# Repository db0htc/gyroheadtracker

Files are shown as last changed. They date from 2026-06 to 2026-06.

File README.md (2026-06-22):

# Gyro Headtracker and mouse control device

  This project is a simple gyro-controlled headtracker and general mouse control tool, made for mounting on hats or anything else that follows head movement.
  It started as something i was making for a friend in Star Citizen who had issues with his hands, but he fell more ill and could not play as much.
  I'm putting it here for anyone else who wants a cool home-made headtracker or gyro assist device for FPS games. You can control your gun movements with it, since it uses mouse input. you can even control the gun gimbals in Star citizen while flying with sticks (very accurately, very quickly), but i do not recommend it. It was simpler to fly normally and use it as a head tracker

  Included in the repository are files for 3D printing the mount for the head tracker PCBs and buttons

 # Bill of Materials:
  
Adafruit ESP32-S3 Feather with 4MB Flash 2MB PSRAM - STEMMA QT / Qwiic PID: 5477
https://www.adafruit.com/product/5477 

Adafruit 9-DOF Orientation IMU Fusion Breakout - BNO085 (BNO080) - STEMMA QT / Qwiic PID: 4754
https://www.adafruit.com/product/4754

STEMMA QT / Qwiic JST SH 4-pin Cable - 100mm Long
https://www.adafruit.com/product/4210 

at the time of this writing, the total cost before shipping is under $50. Not bad for a cheap head tracker with low latency and good accuracy!
Please support Adafruit by buying from them, their code libraries and hardware has made so many projects like this one possible, and
their contributions the arduino ecosystem can not be understated

# Programming:

In the Arduino IDE:
1. install the Adafruit_Tinyusb library
2. install the BNO08x library
3. plug in ESP-32 feather module via USB-C
4. program

# Usage:

1. assemble mount
2. mount mount to hat

3. look at center of monitor and press calibrate button

This project should work with any ESP-32-S3 adjacent board, and any BNO080 gyro using I2C, but i recommend the three links above for plug and play simplicity

The above board is bluetooth capable, enabling a wireless version, but the bluetooth interface for mice is a bit weird and i didn't like it

due to the nature of geometry, the tracking follows a rotational path on a flat surface, so you will get more speed in the center of the screen, but slightly more accuracy and less speed on the edges of the screen. If you have a curved monitor, this is a non issue except on the vertical axis. You might not notice the effect when you edit the variables for mouse control vs head tracking

# Assembly:

the following picture is how i made mine (STL file included, print vertically so the long axis is along the vertical axis of the printer. Designed for printing without supports)

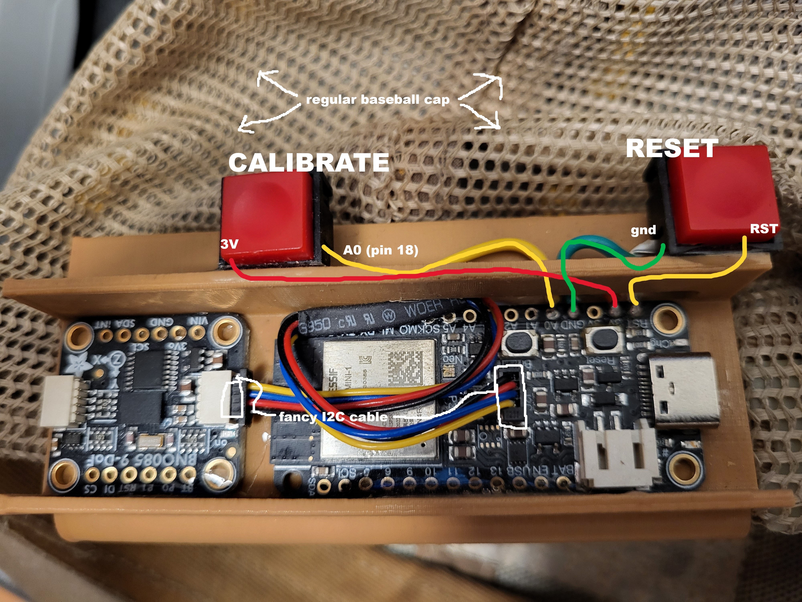
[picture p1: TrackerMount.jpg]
example of mounting

https://github.com/db0htc/gyroheadtracker/blob/main/TrackerMount.jpg

No AI generated code was used in this project. AI was used to look up the normalization formula, which was then hand-typed in

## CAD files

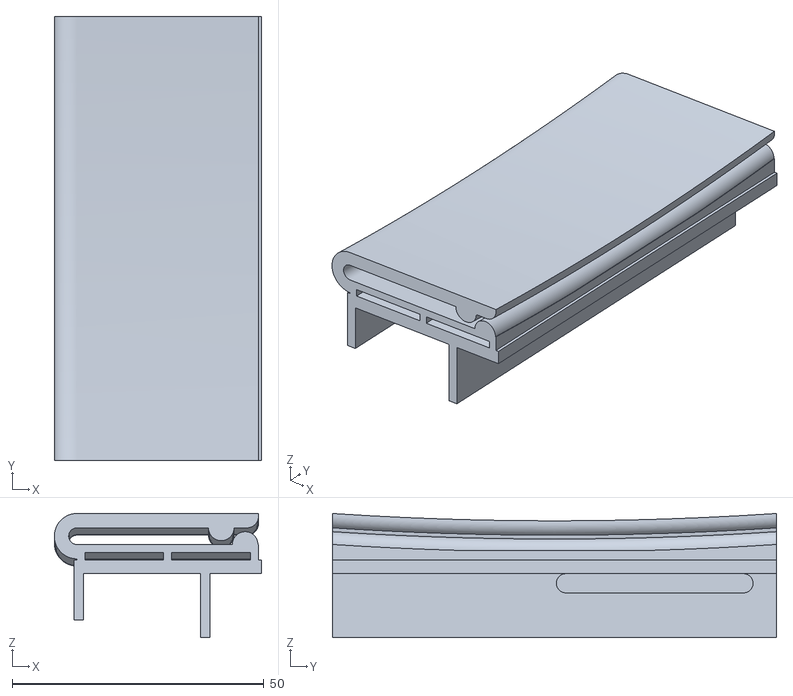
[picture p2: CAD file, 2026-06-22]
diyheadtrackerclip2.STL
41.2 x 88.3 x 24.7

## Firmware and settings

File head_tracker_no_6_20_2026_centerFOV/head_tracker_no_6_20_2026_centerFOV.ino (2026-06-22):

/*
This is a gyro-controlled mouse mover. It also works as a head tracker in some games (i use it for nuclear option and star citizen)
with the right code additions, this could also be used to create a unique joystick input or gamepad input

this used example code as an initial template, originally by Adafruit
who are awesome and deserve good things for how much they bring into the maker community
seriously, chinese products are cheaper but buy Adafruit if you can!

latency is at or less than 10ms (or was)
very accurate, can be tweaked by editing the two variables at the current default values for head tracking:
float FOV = 60;
float sensitivity = 1000;
these variables are found below at lines 64 and 65

an FOV value of 40 and a sensitivity of 500 is better for casual mouse control
FOV value of 40 was obtained by measuring my monitor and distance from my face to the monitor

sensitivity in part is left over from the time i had an absolute position version, 
but it's literally unusable in games due to them using relative positioning of the mouse. 
Might be better for accessibility users on the desktop, but requires additional files i have edited

the included libraries below are necessary for the project to compile

the two pins being used are the reset pin, and pin 18 (A0) for selecting the center of the monitor as the reference point. A0 (pin 18) is pulled low and activated by a button wired to positive
*/
#include <Arduino.h>
#include <Adafruit_BNO08x.h>
#include "Adafruit_TinyUSB.h"

#if defined(ARDUINO_SAMD_CIRCUITPLAYGROUND_EXPRESS) || defined(ARDUINO_NRF52840_CIRCUITPLAY)
const int pin = 4; // Left Button
bool activeState = true;

#elif defined(ARDUINO_FUNHOUSE_ESP32S2)
const int pin = BUTTON_DOWN;
bool activeState = true;

#elif defined PIN_BUTTON1
const int pin = PIN_BUTTON1;
bool activeState = false;

#elif defined(ARDUINO_ARCH_ESP32)
const int pin = 0;
bool activeState = false;

#elif defined(ARDUINO_ARCH_RP2040)
const int pin = D0;
bool activeState = false;
#else
const int pin = A0;
bool activeState = false;
#endif


int16_t lastx = 0;
int16_t lasty = 0;

float rlimitx = 0;
float llimitx = 0;
float ulimity = 0;
float dlimity = 0;
float xcenter = 0;
float ycenter = 0;
float FOV = 60;
float sensitivity = 1000;

const int calbutton = 18;

// HID report descriptor using TinyUSB's template
// Single Report (no ID) descriptor
uint8_t const desc_hid_report[] = {
    TUD_HID_REPORT_DESC_MOUSE()
};

Adafruit_USBD_HID usb_hid;
#define BNO08X_CS 10
#define BNO08X_INT 9
#define FAST_MODE
#define BNO08X_RESET -1

struct euler_t {
  float yaw;
  float pitch;
  float roll;
} ypr;

Adafruit_BNO08x  bno08x(BNO08X_RESET);
sh2_SensorValue_t sensorValue;

sh2_SensorId_t reportType = SH2_GYRO_INTEGRATED_RV;
long reportIntervalUs = 2000;

void setReports(sh2_SensorId_t reportType, long report_interval) {
  if (! bno08x.enableReport(reportType, report_interval)) {
  }
}

void setup(void) {
// for some reason the disconnect/reconnect was necessary on my computer
 digitalWrite(calbutton, HIGH);

 tud_disconnect();

 delay(2000);

 tud_connect();

 delay(2000);

 while (!TinyUSBDevice.isInitialized()) {
    delay(200);
    TinyUSBDevice.begin(0);
  }

 delay(10);     // will pause Zero, Leonardo, etc until serial console opens

  if (!bno08x.begin_I2C()) {
    while (1) { delay(10); }
  }

  setReports(reportType, reportIntervalUs);

  pinMode(pin, activeState ? INPUT_PULLDOWN : INPUT_PULLUP);

  usb_hid.setBootProtocol(HID_ITF_PROTOCOL_MOUSE);
  usb_hid.setPollInterval(2);
  usb_hid.setReportDescriptor(desc_hid_report, sizeof(desc_hid_report));
  usb_hid.setStringDescriptor("TinyUSB Mouse");
  usb_hid.begin();

  if (TinyUSBDevice.mounted()) {
    TinyUSBDevice.detach();
    delay(10);
    TinyUSBDevice.attach();
  }

  delay(100);
}

void quaternionToEuler(float qr, float qi, float qj, float qk, euler_t* ypr, bool degrees = false) {

    float sqr = sq(qr);
    float sqi = sq(qi);
    float sqj = sq(qj);
    float sqk = sq(qk);

    ypr->yaw = atan2(2.0 * (qi * qj + qk * qr), (sqi - sqj - sqk + sqr));
    ypr->pitch = asin(-2.0 * (qi * qk - qj * qr) / (sqi + sqj + sqk + sqr));
    ypr->roll = atan2(2.0 * (qj * qk + qi * qr), (-sqi - sqj + sqk + sqr));

    if (degrees) {
      ypr->yaw *= RAD_TO_DEG;
      ypr->pitch *= RAD_TO_DEG;
      ypr->roll *= RAD_TO_DEG;
    }
}

void quaternionToEulerRV(sh2_RotationVectorWAcc_t* rotational_vector, euler_t* ypr, bool degrees = false) {
    quaternionToEuler(rotational_vector->real, rotational_vector->i, rotational_vector->j, rotational_vector->k, ypr, degrees);
}

void quaternionToEulerGI(sh2_GyroIntegratedRV_t* rotational_vector, euler_t* ypr, bool degrees = false) {
    quaternionToEuler(rotational_vector->real, rotational_vector->i, rotational_vector->j, rotational_vector->k, ypr, degrees);
}

void process_hid() {
  bool btn_pressed = digitalRead(calbutton);

  if (TinyUSBDevice.suspended()) {
    TinyUSBDevice.remoteWakeup();
  }

 if (btn_pressed) {
      delay(100);
        xcenter = ypr.yaw;
        ycenter = ypr.pitch;
        float FOVDIV = FOV / 2;
        ulimity = ycenter - FOVDIV;
        dlimity = ycenter + FOVDIV;
        llimitx = xcenter + FOVDIV;
        rlimitx = xcenter - FOVDIV;
 }
  return;
}

void loop() {

  #ifdef TINYUSB_NEED_POLLING_TASK
  TinyUSBDevice.task();
  #endif

  if (!TinyUSBDevice.mounted()) {
    return;
  }

  static uint32_t ms = 0;
  if (millis() - ms > 10) {
    ms = millis();
    process_hid();
  }

  if (bno08x.wasReset()) {
    setReports(reportType, reportIntervalUs);
  }
  
  if (bno08x.getSensorEvent(&sensorValue)) {
    // in this demo only one report type will be received depending on FAST_MODE define (above)
    switch (sensorValue.sensorId) {
      case SH2_ARVR_STABILIZED_RV:
        quaternionToEulerRV(&sensorValue.un.arvrStabilizedRV, &ypr, true);
      case SH2_GYRO_INTEGRATED_RV:
        // faster (more noise?)
        quaternionToEulerGI(&sensorValue.un.gyroIntegratedRV, &ypr, true);
        break;
    }
    if (usb_hid.ready()) {
    uint8_t const report_id = 0; // no ID
    int16_t const x = (1 - ((ypr.yaw - rlimitx) / (llimitx - rlimitx))) * sensitivity;
    int16_t const y = ((ypr.pitch - ulimity) / (dlimity - ulimity)) * sensitivity;
    int8_t const relx = x - lastx;
    int8_t const rely = y - lasty;
    float const xyratio = (llimitx - rlimitx) / (dlimity - ulimity);
    lastx = x;
    lasty = y;
    usb_hid.mouseMove(report_id, relx, rely);
    /* //debug and development serial monitor printing
    Serial.print("limitset:"); Serial.print(limitset);  Serial.print("\n");
    Serial.print("rlimitx:");  Serial.print(rlimitx); Serial.print("\n");
    Serial.print("ypr.yaw:");  Serial.print(ypr.yaw);  Serial.print("\n");
    Serial.print("llimitx:");  Serial.print(llimitx);  Serial.print("\n");
    Serial.print("ulimity:");  Serial.print(ulimity);  Serial.print("\n");
    Serial.print("ypr.pitch:");  Serial.print(ypr.pitch);  Serial.print("\n");
    Serial.print("dlimity:");  Serial.print(dlimity);  Serial.print("\n"); 
    Serial.print("relx:");  Serial.print(relx);  Serial.print("\n");
    Serial.print("rely:");  Serial.print(rely);  Serial.print("\n");
    Serial.print("lastx:");  Serial.print(lastx);  Serial.print("\n");
    Serial.print("lasty:");  Serial.print(lasty);  Serial.print("\n");
    Serial.print("x:");  Serial.print(x);  Serial.print("\n");
    Serial.print("y:");  Serial.print(y);  Serial.print("\n");
    Serial.print("xyratio:");  Serial.print(xyratio);  Serial.print("\n");
    */
    //delay(100); // for easier serial monitoring
    //usb_hid.ABSmouseMove(report_id, x, y);
  }
  }

}
